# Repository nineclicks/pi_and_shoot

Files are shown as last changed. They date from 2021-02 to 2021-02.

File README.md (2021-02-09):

# Pi & Shoot

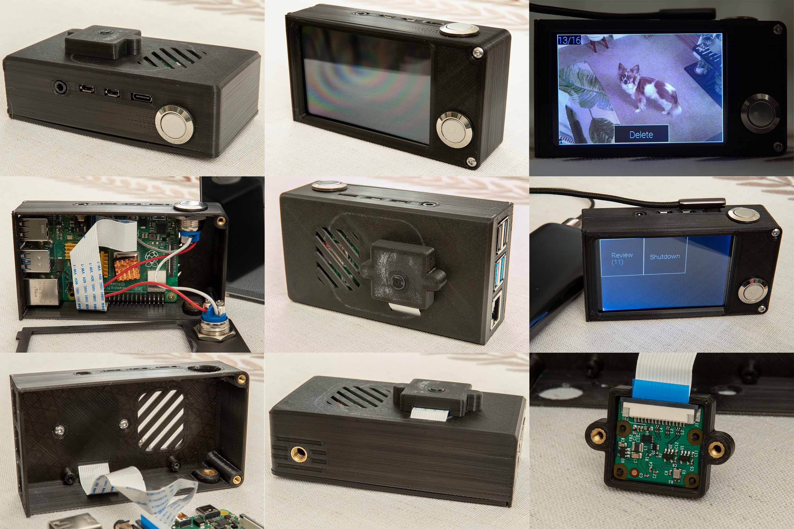
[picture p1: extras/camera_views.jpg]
Project Images

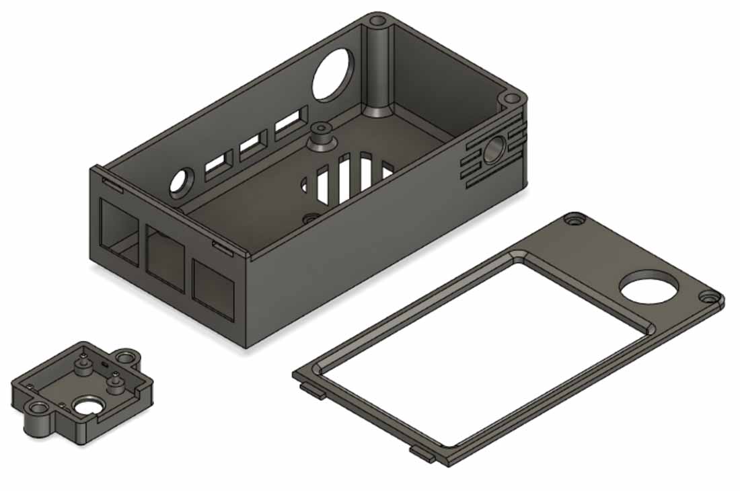
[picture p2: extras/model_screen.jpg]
Model Screenshot


## Building

See `extras` folder for models and part information. Please be aware that this model has tolerances for my printer baked in. I printed with supports on >80 degree overhangs mainly to prevent sagging on the rectangular port holes. It was printed with a 0.6mm nozzle at 0.2mm layer height on an Ender 3.

## Wiring

The two buttons connect board pins 38 (front button) and 40 (top button) to ground. The script uses the Pi's internal pullup resistors.

## Setup

Install `ffmpeg`. Uses ffmpeg to convert png to whatever the framebuffer format is. fbi does not like being called over and over.

Screen is constantly calibrating, just touch all four corners the first time your run before using the menu.

Add user to gpio group, replace `user` with your username to use GPIO without running script as root

```
sudo adduser user gpio
```

Add line to visudo, replace `user` with your username to shutdown without running script as root

```
user ALL=(ALL) NOPASSWD: /sbin/poweroff, /sbin/reboot, /sbin/shutdown
```

I use systemctl to run the camera.py script at startup

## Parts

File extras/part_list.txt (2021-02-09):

Parts:
  Raspberry Pi 4, any mem size with SD card
  Official Raspberry Pi Camera V2 with short cable
  3.5" Raspberry Pi Touch Screen
  4 M3x6 or approx. similar length bolts
  4 screws for mounting the Pi, honestly not sure of the size. They came from another case.
  4 brass threaded inserts M3 X D4.6 X L5.0
  1 1/4 inches-20 x 6mm L x 8mm OD Female Thread Brass Embedment Nuts
  2 16mm Waterproof Momentary Stainless Steel Metal Push Button Switches
  Female dupont cables for Rpi header. With plastic sheaths removed.
  External power source for the Pi

Tools:
  3d printer
  Hex key and/or screwdriver for screws and bolts
  Soldering iron for brass inserts

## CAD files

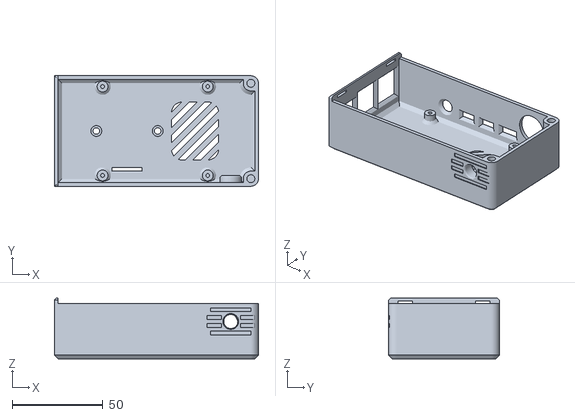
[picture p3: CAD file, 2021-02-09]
extras/pi_cam_body.stl
112.5 x 61.0 x 33.5

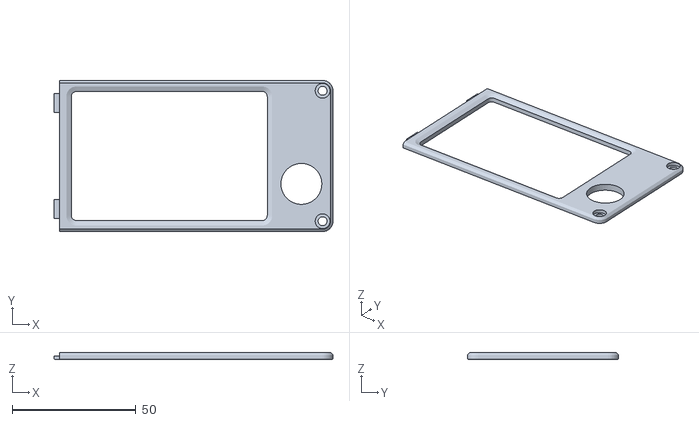
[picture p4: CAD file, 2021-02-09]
extras/pi_cam_face.stl
112.5 x 61.0 x 3.00

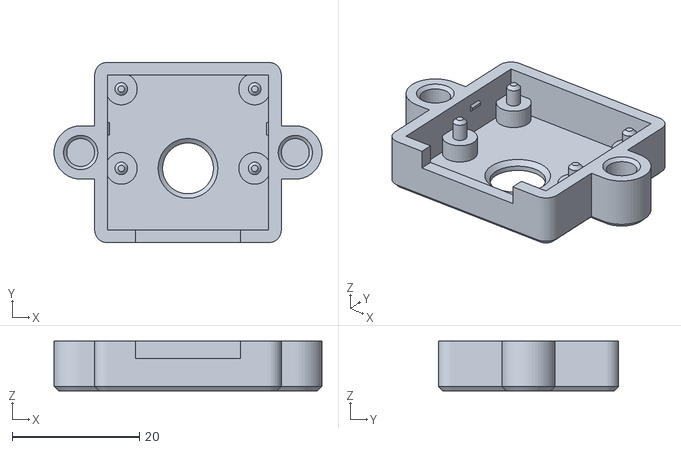
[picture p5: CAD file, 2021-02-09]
extras/pi_cam_mount.stl
42.2 x 28.4 x 7.85

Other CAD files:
extras/pi_cam_screen_case_v14.f3d

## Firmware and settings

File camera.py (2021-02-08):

from touch import touch
from preview import Preview
from buttons import press_menu_button, press_shutter_button
from menu import Menu
import subprocess
from review import get_images, Review

import picamera
from time import time

menu_open = False
review_open = False
menu = Menu()

@touch
def screen_touch(x, y):
    if menu_open:
        menu.press(x, y)

    elif review_open:
        review.press(x, y)

@press_menu_button
def menu_button():
    global menu_open, review_open
    if review_open:
        review_open = False
        menu_open = False
    else:
        menu_open = not menu_open

    if menu_open:
        preview.stop()
        menu.render_menu()

    else:
        preview.start()

@press_shutter_button
def shutter_button():
    if menu_open or review_open:
        menu_button()

    else:
        preview.snap('out/{}.jpg'.format(str(int(time()*1000))))

def shut_down():
    print('shutting down')
    subprocess.run(['sudo', 'shutdown', 'now'])

def start_review():
    global menu_open, review_open, review
    menu_open = False
    review_open = True
    review = Review()

review = None


menu.items = [
        (lambda: 'Review\n({})'.format(len(get_images())), start_review),
        (lambda: 'Shutdown', shut_down),
        ]

preview = Preview((480*6, 320*6), 2)
preview.start()

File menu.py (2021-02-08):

from PIL import Image, ImageDraw, ImageFont
import subprocess
from display import show

class Menu:

    w = 480
    h = 320
    
    btn_w = int(w / 3)
    btn_h = int(h / 2)

    img = None

    items = []

    def __init__(self):
        self.render_menu()

    def render_menu(self):
        self.img = Image.new("RGB", (self.w, self.h)) 
        draw = ImageDraw.Draw(self.img)   
        draw.rectangle((0,0,self.w-1,self.h-1), fill=(0,0,0)) 

        for n in range(len(self.items)):
            self.render_btn(n)

        show(self.img)

    def render_btn(self, n):
        fnt = ImageFont.truetype("Roboto-Thin.ttf", 26)
        btn = Image.new("RGB", (self.btn_w, self.btn_h)) 
        draw = ImageDraw.Draw(btn)
        draw.rectangle((0,0,self.btn_w-1,self.btn_h-1), fill=(0,0,0), outline=(255,255,255))
        txtw, txth = draw.textsize(self.items[n][0](),font=fnt)
        draw.text((int(self.btn_w/2-txtw/2),int(self.btn_h/2-txth/2)), self.items[n][0](),font=fnt, fill=(255,255,255))
        self.img.paste(btn, (self.btn_w * (n % 3), self.btn_h * int(n / 3)))

    def press(self, x, y):
        y = y
        bx = int(x / self.btn_w)
        by = int(y / self.btn_h)

        b_num = bx + by * 3
        try:
            self.items[b_num][1]()
        except Exception as e:
            print(str(e))
